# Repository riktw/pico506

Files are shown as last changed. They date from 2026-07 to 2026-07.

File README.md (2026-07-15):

# Pico506 changes

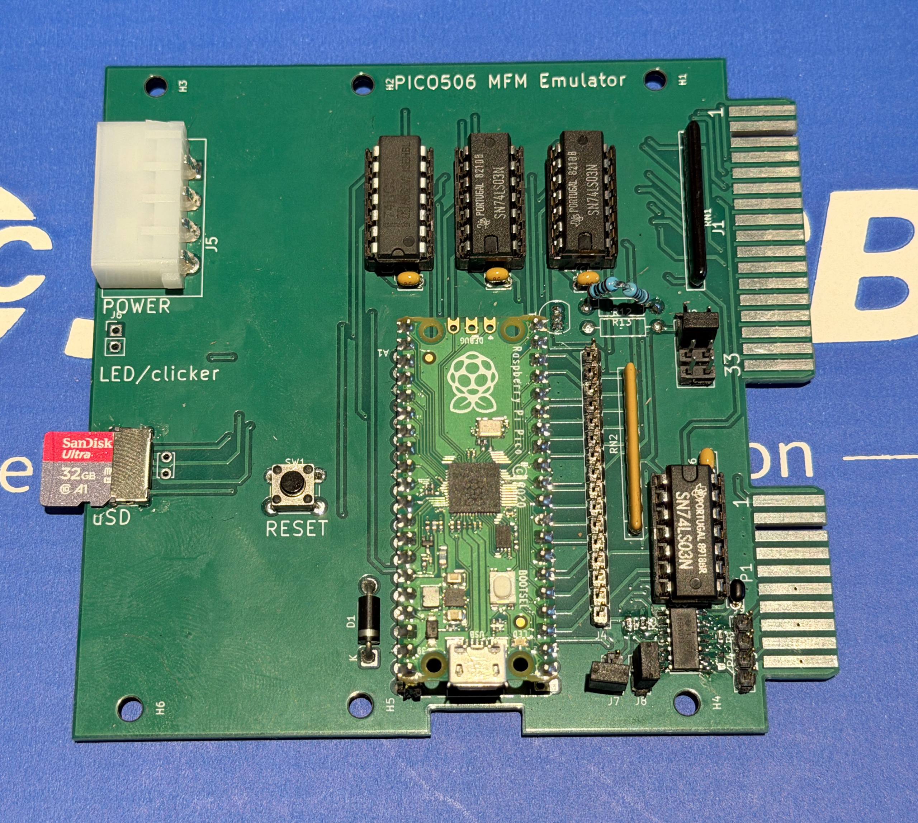
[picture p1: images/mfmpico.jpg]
mfmpico


This repo adds a PCB that can be used to replace an existing MFM HDD.
It also adds support for 4 HEAD lines instead of 2 and for drive select support.

This is tested with an MFM emulator, but does not always work in machines, and has not been tested with many computers. Use at your own risk!
If you own a LOT of MFM computers and want to help test it, please make an issue or contact me!

The main issue seems to be in machines that unselect and reselect the drive after every command.

# Pico506

The smallest and cheapest ST-506/RLL/MFM hard drive emulator.

*Read the full story of building this
project: [Emulating a 1987 proprietary RLL hard drive](https://kuba.szczodrzynski.pl/posts/toshiba-t1200/rll-hdd-emulator/)*

## Introduction

Pico506 is a simple, yet universal emulator of old RLL/MFM hard drives using the ST-506 signaling and control interface.

It is based on a Raspberry Pi Pico (RP2040 chip), which makes it extremely cheap to build. Thanks to the PIO
peripheral (Programmable I/O), it also offers pretty good performance and stability.

While it's primarily built to emulate a proprietary RLL(2,7) hard drive made by JVC (JD-3824), which uses a proprietary
26-pin interface, it should also be able to emulate any other drive using ST-506-compatible signaling.

As an added bonus, the Pico506 outputs a signal to drive a small piezo buzzer. This is inspired by
the [HDD Clicker](https://www.vogons.org/viewtopic.php?t=90047) and makes the emulator output "click" sounds whenever
the virtual drive is accessed.

## Prerequisites

While there is no dedicated hardware (PCB) for this project (yet), it is pretty simple to build on a perfboard. The
basic parts required are:

- Raspberry Pi Pico (or similar board with RP2040),
- SD/microSD card and a matching socket (MMC is not supported),
- a connector for the HDD controller of your PC,
- a level shifter/inverter circuit (more on that later),
- a piezo buzzer (without a built-in generator) - optional.

## Interface

The ST-506 interface uses a few control signals - it's probably best to refer to, for example,
Wikipedia ([ST-506/ST-412](https://en.wikipedia.org/wiki/ST-506/ST-412)) to learn more about the control interface.

At this point it's also worth to know the definitions of these common terms:

- **track** - a string of bits (flux transitions) stored on one side of a single HDD platter,
- **head** - a magnetic reading/writing head (like in a cassette player) that accesses one side of a single platter,
- **cylinder** - used to refer to the same track on all sides and all platters; in other words,
  `track length * head count = cylinder length`,
- **sector** - a logical part of one track that holds actual data.

To summarize, here are the most important control signals:

- `DRIVE_SELECT0/1/2/3` - selects one of at most four drives that the PC controller wants to talk to,
- `DRIVE_SELECTED` - indicates that the drive exists and is now selected,
- `HEAD_SELECT0/1/2/3` - up to four lines, which together form a 4-bit number of the currently selected head,
- `READY` - whether the drive has finished the spin-up,
- `TRACK_0` - whether the read/write head is positioned on track/cylinder 0,
- `INDEX` - pulse indicating the beginning of the current track (i.e. next sector will be the first on this track),
- `STEP` - performs a single-track step in the direction indicated by `DIR_IN`,
- `SEEK_COMPLETE` - whether the requested seek has been completed,
- `WRITE_GATE` - makes the head write data to the current track,
- `WRITE_FAULT` - indicates a problem during writing.

You might have noticed that the control signals are usually prefixed by `/` or `~`. This means that they are
active-low - a low voltage (~0V) on the line means "active", and high voltage (~5V) means "inactive". More on that
later.

The data signals are raw bit streams of magnetic flux transitions of the HDD's platters. The bits themselves, however,
depend on the type of encoding used in a particular hard drive -
see [Run-length limited](https://en.wikipedia.org/wiki/Run-length_limited) (RLL), or one of its common
variants, [Modified frequency modulation](https://en.wikipedia.org/wiki/Modified_frequency_modulation) (MFM).

Because the control signals are usually the same (or similar) across different drives (even when using different
encodings), Pico506 doesn't actually care about the data stored on the drive.

Instead, it transparently captures bit streams on the `WRITE` line and outputs them back on the `READ` line. The bit
data of the currently loaded cylinder is kept in RAM. Upon seeking, the modified data (if any) is written to the SD
card, and a new cylinder is loaded.

## Pin mapping

This is the default GPIO mapping used in the published source code. It can be changed freely (in `config.h`), under a
condition that `INDEX` and `SERVO_GATE` are using adjacent GPIOs (if you're using that signal, that is).

| GPIO | Direction | Function |
|---|---|---|
| GP0  | OUT | UART TX |
| GP1  | IN | UART RX |
| GP2  | IN | HDD `WRITE_GATE` |
| GP3  | IN | HDD `WRITE` |
| GP4  | IN | HDD `HEAD_1` |
| GP5  | OUT | HDD `READ` |
| GP6  | OUT | HDD `INDEX` |
| GP7  | OUT | HDD `SERVO_GATE` |
| GP8  | OUT | HDD `READY` |
| GP9  | OUT | HDD `TRACK_0` |
| GP10 | OUT | HDD `SEEK_COMPLETE` |
| GP11 | IN | HDD `SELECT` |
| GP12 | IN | HDD `STEP` |
| GP13 | IN | HDD `DIR_IN` |
| GP15 | OUT | Buzzer (optional) |
| GP18 | OUT | SD `SCK` |
| GP19 | OUT | SD `MOSI` |
| GP20 | IN | SD `MISO` |
| GP21 | OUT | SD `CS` |

All the signals use **active-high** logic - that is, **opposite** to the normal ST-506 interface. This makes it
necessary to use an inverter, which fortunately also solves the problem of level shifting (3.3V vs 5V).

The inverter chip must be open-drain/open-collector. I personally tested it with 74LS05 and found that it works great.

Here's a simple connection diagram using two 74LS05s:

```
                                    +---------+
                       /WRITE_GATE -| o       |- +5V
 +3V3 ------[/\/\1k/\/\]------ GP2 -|         |- /WRITE
                           /HEAD_1 -|         |- GP3 ------[/\/\1k/\/\]------ +3V3
 +3V3 ------[/\/\1k/\/\]------ GP4 -|         |- GP5
                               GP6 -|         |- /READ ------[/\/\470/\/\]------ +5V
                            /INDEX -|         |- GP7
                               GND -|         |- /SERVO_GATE
                                    +---------+

                                    +---------+
                               GP8 -| o       |- +5V
                            /READY -|         |- GP9
                              GP10 -|         |- /TRACK_0
                    /SEEK_COMPLETE -|         |- /SELECT
                             /STEP -|         |- GP11 ------[/\/\1k/\/\]------ +3V3
+3V3 ------[/\/\1k/\/\]------ GP12 -|         |- /DIR_IN
                               GND -|         |- GP13 ------[/\/\1k/\/\]------ +3V3
                                    +---------+
```

The 1 kOhm pull-up resistors are necessary to make the inverters fast enough when converting 5V to 3.3V.

The 470 Ohm resistor on the `/READ` line is theoretically optional, and you might need to tweak the value a little bit.
A lower value makes the resulting inverted pulses "faster" (i.e. propagation is quicker, so pulses get longer).

As for the `SERVO_GATE` signal (which is not part of the ST-506 specification) - it's a special signal required for the
RLL(2,7) JVC JD-3824 drive. These drivers have 17 "pulses" per track, with 2 sectors between each "pulse". This pulse is
exactly what the `SERVO_GATE` signal means - between every two `INDEX` pulses, there are 17 `SERVO_GATE` pulses. For
emulating an ST-506 drive, this can be left unconnected.

Here's a little visualization of the JVC RLL interface:

```
INDEX         ___/‾‾‾‾‾‾‾‾‾‾‾‾\________________________________________________________
SERVO_GATE    ___/‾‾‾‾‾‾‾‾‾‾‾‾\____________________________________/‾‾‾‾‾‾‾‾‾‾‾‾\_______
READ          .../‾‾‾‾‾‾‾‾‾‾‾‾\....<...data...>....<...data...>..../‾‾‾‾‾‾‾‾‾‾‾‾\....... (repeat 17 times)
```

## Data configuration

Now, this is something that is specific to each hard drive, as it defines the geometry and timing of the signals.

The emulator assumes that each "logical" data bit encodes as 2 bits in MFM and RLL encodings. The entries named `LBYTES`
represent counts of "logical" data bytes (e.g. 512 for sector length).

To convert "logical" bytes into a real duration (in nanoseconds), use the following formula:

```
LENGTH_NS = (1 / (DATA_RATE * 2)) * (LBYTES * 8 * 2) * 1000 * 1000 * 1000
```

(8 - bits per byte, 2 - overhead of RLL/MFM encoding).

Configuration options (`config.h`) that should be adapted to each drive type:

- `DATA_RATE` - data transfer rate, in bits/second. Most MFM drives use 5 Mbps, and RLL(2,7) drives use 7.5 Mbps.
- `MARK_LBYTES` - length of the `INDEX` and `SERVO_GATE` pulses; use the formula above to convert. If in doubt, go for
  around 50 microseconds = 50,000 nanoseconds.
- `HEADER_LBYTES` - length of the sector header; using around 100 should be good.
- `DATA_LBYTES` - length of the sector data; should be 512 for most drives.
- `SECTORS_PER_PULSE` - see: `SERVO_GATE` description above. Use `1` unless emulating a JD-3824 drive, then use `2`.
- `PULSES_PER_TRACK` - in other words: `sectors per track = sectors per pulse * pulses per track`.
- `HEADS` - self-explanatory.
- `CYLINDERS` - self-explanatory.

## Limitations

1. Since the emulator doesn't decode RLL/MFM data (it uses raw bit streams), the total sector count in a single cylinder
   cannot exceed the available RAM space. To calculate total RAM usage for one cylinder (in bytes), use:
   `(MARK_LBYTES + (HEADER_LBYTES + SECTOR_LBYTES) * SECTORS_PER_PULSE) * PULSES_PER_TRACK * 8 * 2 * HEADS / 8`.
2. Because of above, the RAM usage for a single cylinder is about 2.5x bigger than the actual data stored in these bits.
   This also makes seek times longer, because more data has to be read from the SD card.
3. Only two heads are supported so far (the head switching code for more than 1 bit is not implemented). This is,
   however, pretty easy to fix - just add more GPIOs and supporting code in `st506_head_irq()`.
4. Drive Select is not supported, i.e. the drive acts as if it was selected all the time. It shouldn't be a problem
   when
   using a single drive with an RLL/MFM controller card, but multiple drives will conflict with each other. A proper
   solution would be to use NAND gates to offload the drive selection from software.
5. `WRITE_FAULT` is not implemented.
6. There is currently no way to change the HDD image on-the-fly; the image filename is hardcoded in `pico506.c`.

## Screenshots

Here are some screenshots of the RLL(2,7) emulator in action, in a Toshiba T1200:

CheckIt
MS-DOS Diagnostics

## License

This project is licensed under the [General Public License](LICENSE).

Copyright © 2025 Kuba Szczodrzyński

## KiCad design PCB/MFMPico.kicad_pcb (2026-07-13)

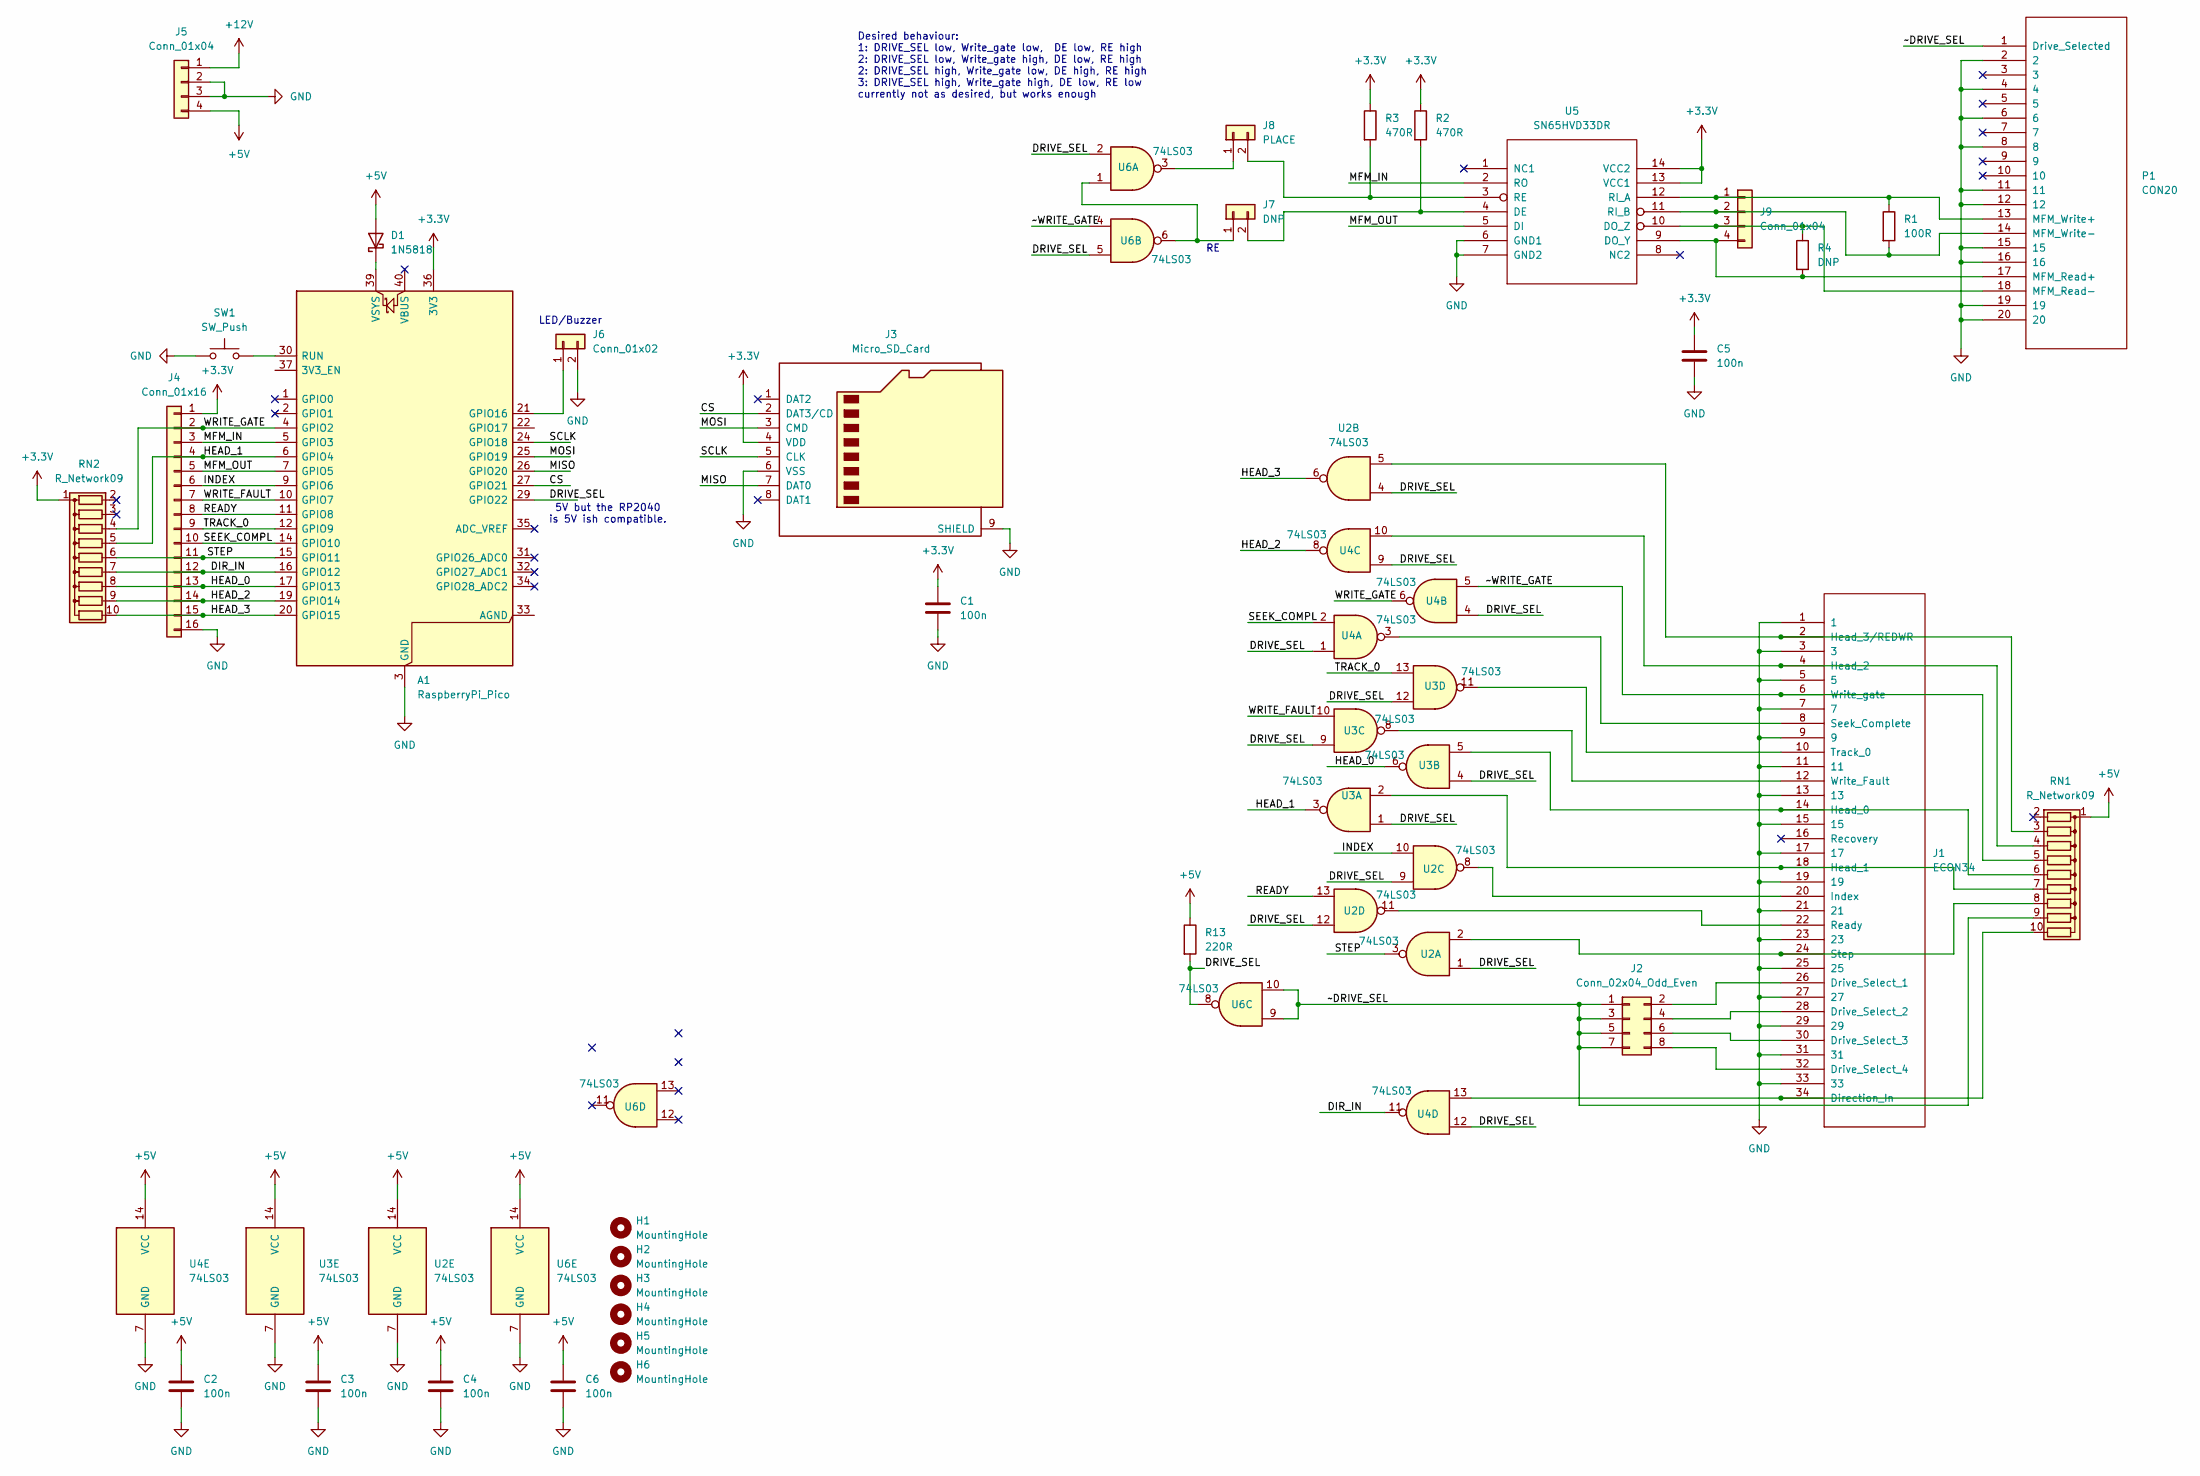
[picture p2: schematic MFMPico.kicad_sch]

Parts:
A1: RaspberryPi_Pico; RaspberryPi_Pico_Common_Unspecified
C1, C2, C3, C4, C5, C6: 100n; C_Disc_D3.4mm_W2.1mm_P2.50mm
D1: 1N5818; D_DO-41_SOD81_P10.16mm_Horizontal
H1, H2, H3, H4, H5, H6: MountingHole; MountingHole_3.2mm_M3
J1: ECON34
J2: Conn_02x04_Odd_Even; PinHeader_2x04_P2.54mm_Vertical
J3: Micro_SD_Card; microSD Hanbo Electronic TF-018; JLC C164170
J4: Conn_01x16; PinHeader_1x16_P2.54mm_Vertical
J5: Conn_01x04; DRVPWR
J6: Conn_01x02; PinHeader_1x02_P2.54mm_Vertical
J7: DNP; PinHeader_1x02_P2.54mm_Vertical
J8: PLACE; PinHeader_1x02_P2.54mm_Vertical
J9: Conn_01x04; PinHeader_1x04_P2.54mm_Vertical
P1: CON20; econ20
R1: 100R; R_0603_1608Metric
R2, R3: 470R; R_0603_1608Metric
R4: DNP; R_0603_1608Metric
R13: 220R; R_Axial_DIN0207_L6.3mm_D2.5mm_P10.16mm_Horizontal
RN1, RN2: R_Network09; R_Array_SIP10
SW1: SW_Push; SW_PUSH_6mm
U2, U3, U4, U6: 74LS03; DIP-14_W7.62mm
U5: SN65HVD33DR; SOIC-14_3.9x8.7mm_P1.27mm

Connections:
+3.3V: A1.36 (3V3), C1.1, C5.1, J3.4 (VDD), J4.1, R2.1, R3.1, RN2.1 (common), U5.13 (VCC1), U5.14 (VCC2)
+5V: C2.1, C3.1, C4.1, C6.1, D1.2 (A), J5.4, R13.1, RN1.1 (common), U2.14 (VCC), U3.14 (VCC), U4.14 (VCC), U6.14 (VCC)
+12V: J5.1
/CS: A1.27 (GPIO21), J3.2 (DAT3/CD)
/DIR_IN: A1.16 (GPIO12), J4.12, RN2.7 (R6), U4.11
/DRIVE_SEL: A1.29 (GPIO22), R13.2, U2.1, U2.4, U2.9, U2.12, U3.1, U3.4, U3.9, U3.12, U4.1, U4.4, U4.9, U4.12, U6.2, U6.5, U6.8
/HEAD_0: A1.17 (GPIO13), J4.13, RN2.8 (R7), U3.6
/HEAD_1: A1.6 (GPIO4), J4.4, RN2.5 (R4), U3.3
/HEAD_2: A1.19 (GPIO14), J4.14, RN2.9 (R8), U4.8
/HEAD_3: A1.20 (GPIO15), J4.15, RN2.10 (R9), U2.6
/INDEX: A1.9 (GPIO6), J4.6, U2.10
/MFM_IN: A1.5 (GPIO3), J4.3, U5.2 (RO)
/MFM_OUT: A1.7 (GPIO5), J4.5, U5.5 (DI)
/MISO: A1.26 (GPIO20), J3.7 (DAT0)
/MOSI: A1.25 (GPIO19), J3.3 (CMD)
/READY: A1.11 (GPIO8), J4.8, U2.13
/SCLK: A1.24 (GPIO18), J3.5 (CLK)
/SEEK_COMPL: A1.14 (GPIO10), J4.10, U4.2
/STEP: A1.15 (GPIO11), J4.11, RN2.6 (R5), U2.3
/TRACK_0: A1.12 (GPIO9), J4.9, U3.13
/WRITE_FAULT: A1.10 (GPIO7), J4.7, U3.10
/WRITE_GATE: A1.4 (GPIO2), J4.2, RN2.4 (R3), U4.6
/~DRIVE_SEL: J2.1, J2.3, J2.5, J2.7, P1.1 (Drive_Selected), RN1.9 (R8), U6.9, U6.10
/~WRITE_GATE: J1.6 (Write_gate), RN1.5 (R4), U4.5, U6.4
GND: A1.3 (GND), A1.8 (GND), A1.13 (GND), A1.18 (GND), A1.23 (GND), A1.28 (GND), A1.38 (GND), C1.2, C2.2, C3.2, C4.2, C5.2, C6.2, J1.1, J1.3, J1.5, J1.7, J1.9, J1.11, J1.13, J1.15, J1.17, J1.19, J1.21, J1.23, J1.25, J1.27, J1.29, J1.31, J1.33, J3.6 (VSS), J3.9 (SHIELD), J4.16, J5.2, J5.3, J6.2, P1.2, P1.4, P1.6, P1.8, P1.11, P1.12, P1.15, P1.16, P1.19, P1.20, SW1.1, U2.7 (GND), U3.7 (GND), U4.7 (GND), U5.6 (GND1), U5.7 (GND2), U6.7 (GND)
unnamed: A1.21 (GPIO16), J6.1
unnamed: A1.30 (RUN), SW1.2
unnamed: A1.39 (VSYS), D1.1 (K)
unnamed: J1.34 (Direction_In), RN1.10 (R9), U4.13
unnamed: J1.26 (Drive_Select_1), J2.2
unnamed: J1.28 (Drive_Select_2), J2.4
unnamed: J1.30 (Drive_Select_3), J2.6
unnamed: J1.32 (Drive_Select_4), J2.8
unnamed: J1.14 (Head_0), RN1.6 (R5), U3.5
unnamed: J1.18 (Head_1), RN1.7 (R6), U3.2
unnamed: J1.4 (Head_2), RN1.4 (R3), U4.10
unnamed: J1.2 (Head_3/REDWR), RN1.3 (R2), U2.5
unnamed: J1.20 (Index), U2.8
unnamed: J1.22 (Ready), U2.11
unnamed: J1.8 (Seek_Complete), U4.3
unnamed: J1.24 (Step), RN1.8 (R7), U2.2
unnamed: J1.10 (Track_0), U3.11
unnamed: J1.12 (Write_Fault), U3.8
unnamed: J7.1, U6.1, U6.6
unnamed: J7.2, R2.2, U5.4 (DE)
unnamed: J8.1, U6.3
unnamed: J8.2, R3.2, U5.3 (RE)
unnamed: J9.1, P1.13 (MFM_Write+), R1.1, U5.12 (RI_A)
unnamed: J9.2, P1.14 (MFM_Write-), R1.2, U5.11 (RI_B)
unnamed: J9.3, P1.18 (MFM_Read-), R4.1, U5.10 (DO_Z)
unnamed: J9.4, P1.17 (MFM_Read+), R4.2, U5.9 (DO_Y)

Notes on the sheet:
Desired behaviour: 1: DRIVE_SEL low, Write_gate low, DE low, RE high 2: DRIVE_SEL low, Write_gate high, DE low, RE high 2: DRIVE_SEL high, Write_gate low, DE high, RE high 3: DRIVE_SEL high, Write_gate high, DE low, RE low currently not as desired, but works enough
LED/Buzzer
5V but the RP2040 is 5V ish compatible.

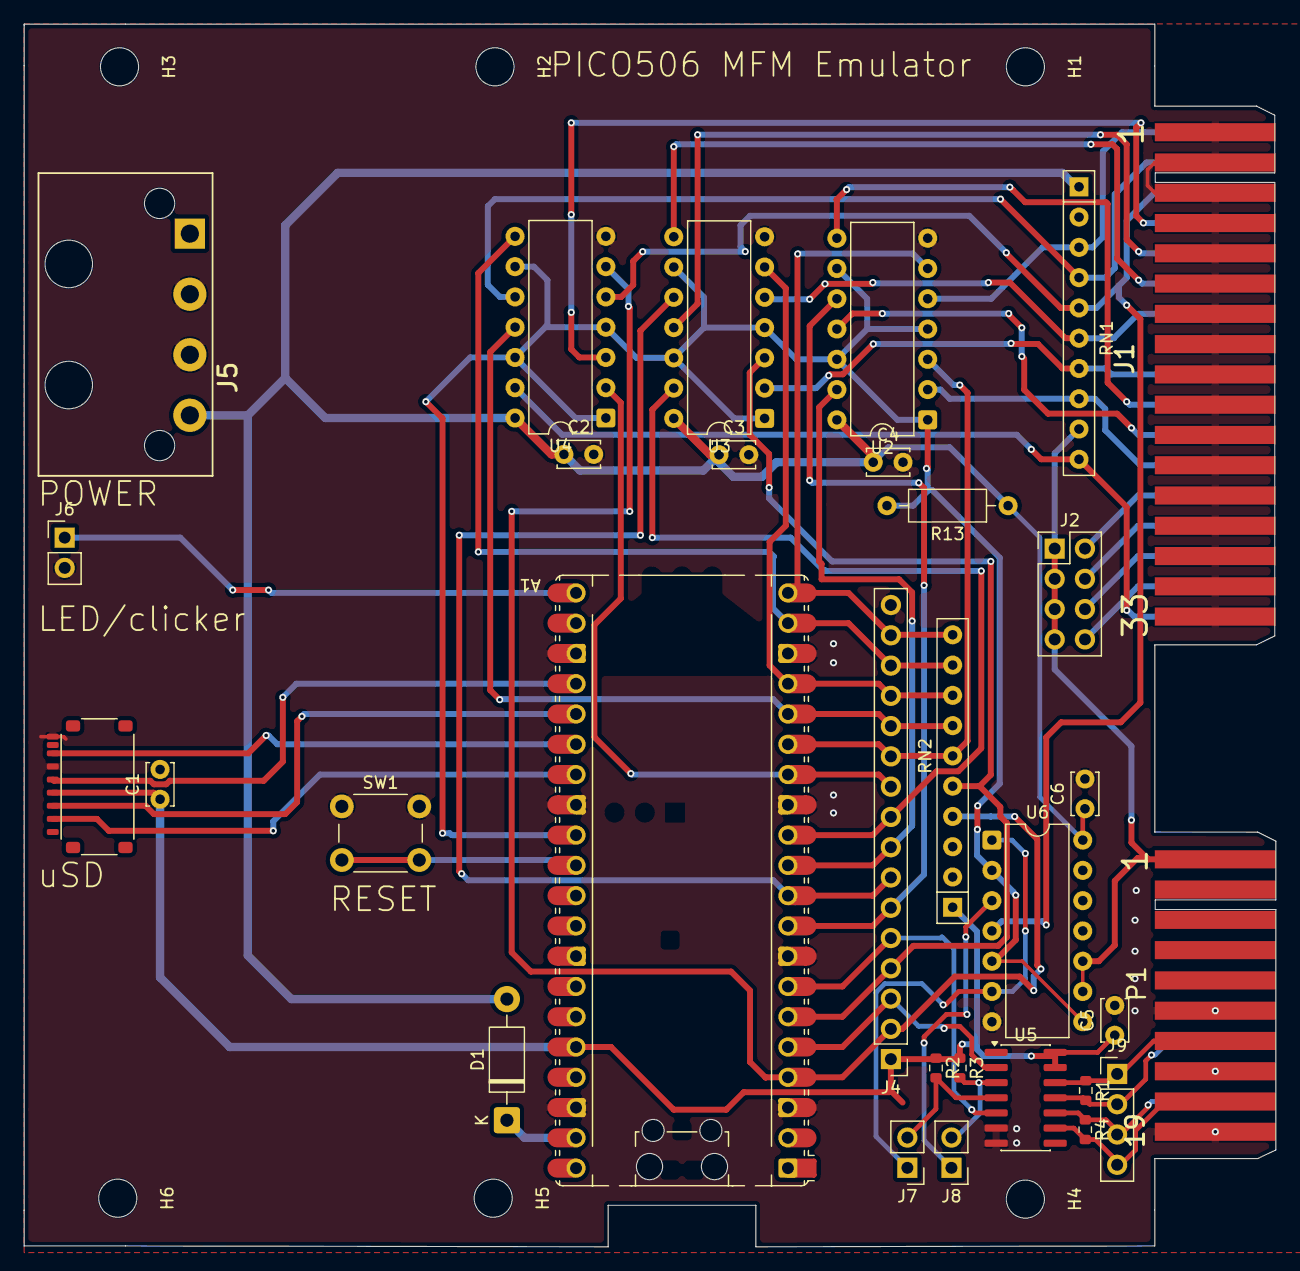
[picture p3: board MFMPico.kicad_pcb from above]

Board: 2 copper layers, 105.0 x 102.6 mm, 37 parts (0 on the bottom side), 50 nets.

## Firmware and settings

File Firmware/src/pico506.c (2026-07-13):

// Copyright (c) Kuba Szczodrzyński 2025-8-4.

#include "pico506.h"

int main() {
	bool oc = set_sys_clock_khz(200000, true);
	stdio_init_all();
	sleep_ms(3000);

	LT_I("OC result: %x", oc);
	pico506_t *pico = malloc(sizeof(*pico));
	memset(pico, 0, sizeof(*pico));

	LT_I("Initializing SPI...");
	pico->storage.sd.spi.sck_pin = PIN_SD_SCK;
	pico->storage.sd.spi.tx_pin	 = PIN_SD_MOSI;
	pico->storage.sd.spi.rx_pin	 = PIN_SD_MISO;
	pico->storage.sd.spi.cs_pin	 = PIN_SD_CS;
	pico->storage.sd.spi.use_dma = true;
	sd_spi_init(&pico->storage.sd, 25 * 1000 * 1000);

	uint retry_ms = 5000;
	while (1) {
		if (storage_init(pico) != 0)
			goto retry;
		if (storage_open(pico, "/HDD.RLL") != 0)
			goto retry;

		if (pico->storage.file_size != DRIVE_BYTES) {
			LT_E("Image file size invalid, found %u bytes, expected %u bytes", pico->storage.file_size, DRIVE_BYTES);
			storage_close(pico);
			goto retry;
		}
		LT_I("Image file size OK");

		break;

	retry:
		LT_E("Retrying in %u ms...", retry_ms);
		sleep_ms(retry_ms);
	}

	st506_start(pico);

	LT_I(
		"Emulator initialized - C/H/S: %u/%u/%u, data rate: %.1f Mb/s",
		CYLINDERS,
		HEADS,
		SECTORS_PER_PULSE * PULSES_PER_TRACK,
		(double)DATA_RATE / 1e6
	);

	while (1) {
		st506_loop(pico);
	}
}

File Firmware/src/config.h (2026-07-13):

// Copyright (c) Kuba Szczodrzyński 2025-8-4.

#pragma once

// MFM data
#define PIN_READ		  5
#define PIN_WRITE		  3
// Control Input
#define PIN_WRITE_GATE	  2
#define PIN_HEAD_0		  13
#define PIN_HEAD_1		  4
#define PIN_HEAD_2		  14
#define PIN_HEAD_3		  15
#define PIN_DIR_IN		  12
#define PIN_STEP		  11
#define DEVICE_SELECT	  17
// Control Output
#define PIN_SEEK_COMPLETE 10
#define PIN_SERVO_GATE	  22 // unused on MFM
#define PIN_INDEX		  6
#define PIN_WRITEFAULT	  7
#define PIN_TRACK_0		  9
#define PIN_READY		  8
// Buzzer
#define PIN_BUZZER		  16 // moved to 16 from 15
// SD Card
#define PIN_SD_SCK		  18
#define PIN_SD_MOSI		  19
#define PIN_SD_MISO		  20
#define PIN_SD_CS		  21

#define DATA_RATE		  5000000
#define MARK_LBYTES		  120
#define HEADER_LBYTES	  120 // 100 for 512b sectors, 70 for 256b sectors
#define DATA_LBYTES		  512
#define SECTORS_PER_PULSE 1
#define PULSES_PER_TRACK  17
#define HEADS			  2
#define CYLINDERS		  322

#define MARK_BITS	(MARK_LBYTES * 8 * 2)
#define SECTOR_BITS ((HEADER_LBYTES + DATA_LBYTES) * 8 * 2)
#define PULSE_BITS	(MARK_BITS + SECTOR_BITS * SECTORS_PER_PULSE)
#define TRACK_BITS	(PULSE_BITS * PULSES_PER_TRACK)

#define MARK_WORDS		(MARK_BITS / 32)
#define SECTOR_WORDS	(SECTOR_BITS / 32)
#define PULSE_WORDS		(PULSE_BITS / 32)
#define TRACK_BYTES		(TRACK_BITS / 8)
#define TRACK_WORDS		(TRACK_BYTES / 4)
#define CYLINDER_BYTES	(TRACK_BYTES * HEADS)
#define CYLINDER_BLOCKS (((CYLINDER_BYTES - 1) / 512) + 1)
#define TRACK_BLOCKS	(CYLINDER_BLOCKS / HEADS)
#define DRIVE_BYTES		(CYLINDER_BYTES * CYLINDERS)

#define IDLE_TIMEOUT 5000

#define CYL_INVALID 2048

#define PIO_RDDT pio0
#define PIO_RDGT pio0
#define PIO_STEP pio0
#define PIO_WRDT pio1
#define PIO_WRGT pio1
#define PIO_WRRM pio1

#define SM_RDDT	 0
#define SM_RDGT	 1
#define SM_STEP	 2
#define SM_WRDT	 0
#define SM_WRGT	 1
#define SM_WRRMC 2
#define SM_WRRMA 3

#define PIO_SM_RDDT	 PIO_RDDT, SM_RDDT
#define PIO_SM_RDGT	 PIO_RDGT, SM_RDGT
#define PIO_SM_STEP	 PIO_STEP, SM_STEP
#define PIO_SM_WRDT	 PIO_WRDT, SM_WRDT
#define PIO_SM_WRGT	 PIO_WRGT, SM_WRGT
#define PIO_SM_WRRMC PIO_WRRM, SM_WRRMC
#define PIO_SM_WRRMA PIO_WRRM, SM_WRRMA

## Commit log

2026-05-24 Added initial pcb, finished the code move
    [MFMPico.kicad_pcb, MFMPico.kicad_sch, rp2040.cfg]
2026-05-25 Mostly up to date PCB
    [MFMPico.kicad_pcb, MFMPico.kicad_sch]
2026-05-27 last changes before ordering
    [MFMPico.kicad_pcb]
2026-07-13 Step not a pio program anymore, validated with mfm emulator.
    [MFMPico.kicad_pcb, MFMPico.kicad_sch]
2026-07-13 Added readme section, enabled error for storage not the right size again
    [pico506.c]
2026-07-15 Added a pcb photo
2026-08-11 moving to nor gates for drive sel slowly
    [MFMPico.kicad_pcb, MFMPico.kicad_sch]
2026-08-18 wip on nor gate version
    [MFMPico.kicad_pcb, MFMPico.kicad_sch]
2026-10-16 New PCB works, apart from an odd low level format issue
